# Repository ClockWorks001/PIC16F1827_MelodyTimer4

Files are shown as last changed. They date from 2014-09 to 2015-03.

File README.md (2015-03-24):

# PIC16F1827 Melody Timer Project.
---
This is a simple kitchen/cooking timer by [PIC16F1827][1].
It can choose which of 3 minutes, 5 minutes and 10 minutes.

## Description

This is a simple kitchen/cooking timer by [PIC16F1827][1].
It can choose which of 3 minutes, 5 minutes and 10 minutes.
When it became end of time, it sounds a melody.

I use following peripherals for this Melody Timer project.
  *TMR1* (with interrupt. It makes 1mil second interval.)
  *TMR2*
  *ECCP2*(with TMR2. I use it for PWM output. It buzz a piezo sounder.)
  *GPIO*(input x2 for Switches, output x3 for LED1, LED2, LED3)

Other references.
  <https://docs.google.com/spreadsheets/d/1fajrvUh0QQHbjQNBCf9UKNRYu8I2-zE32fsanEHT9bc/edit?usp=sharing>

## Demo

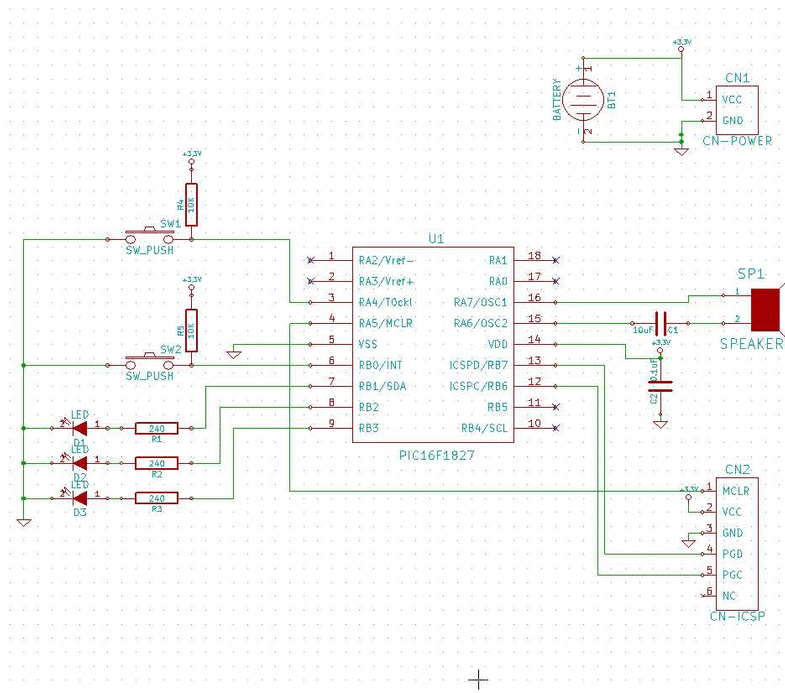
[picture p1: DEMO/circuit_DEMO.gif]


## Prerequisites

I created this project using the free versions of the following tools:
 * [Microchip MPLAB X][2] (v2.3)
 * [Microchip XC8 Compiler][3] (v1.32)
 * [MPLAB Code Configurator][4] (installed as plugin within MPLAB X)
 * [KICAD][6] (BZR4022)

You will need to download and install these tools appropriately before you
can open this project and build it.
I use the [Microchip MPLAB PICkit3 In-Circuit Debugger][5] to program
the chip and debug it.  

## Licence

[MIT](https://github.com/tcnksm/tool/blob/master/LICENCE)

## Author

Hiroshi Murakami  
<https://github.com/ClockWorks001>  

[1]: http://www.microchip.com/wwwproducts/Devices.aspx?dDocName=en538963 "PIC16F1827"
[2]: http://www.microchip.com/pagehandler/en-us/family/mplabx/ "MPLAB X"
[3]: http://www.microchip.com/pagehandler/en_us/devtools/mplabxc/ "MPLAB XC Compilers"
[4]: http://www.microchip.com/pagehandler/en-us/press-release/microchips-free-code-configura.html "MPLAB Code Configurator"
[5]: http://www.microchip.com/Developmenttools/ProductDetails.aspx?PartNO=PG164130 "MPLAB PICkit3 In-Circuit Debugger"
[6]: http://www.kicad-pcb.org/display/KICAD/KiCad+EDA+Software+Suite "KICAD"

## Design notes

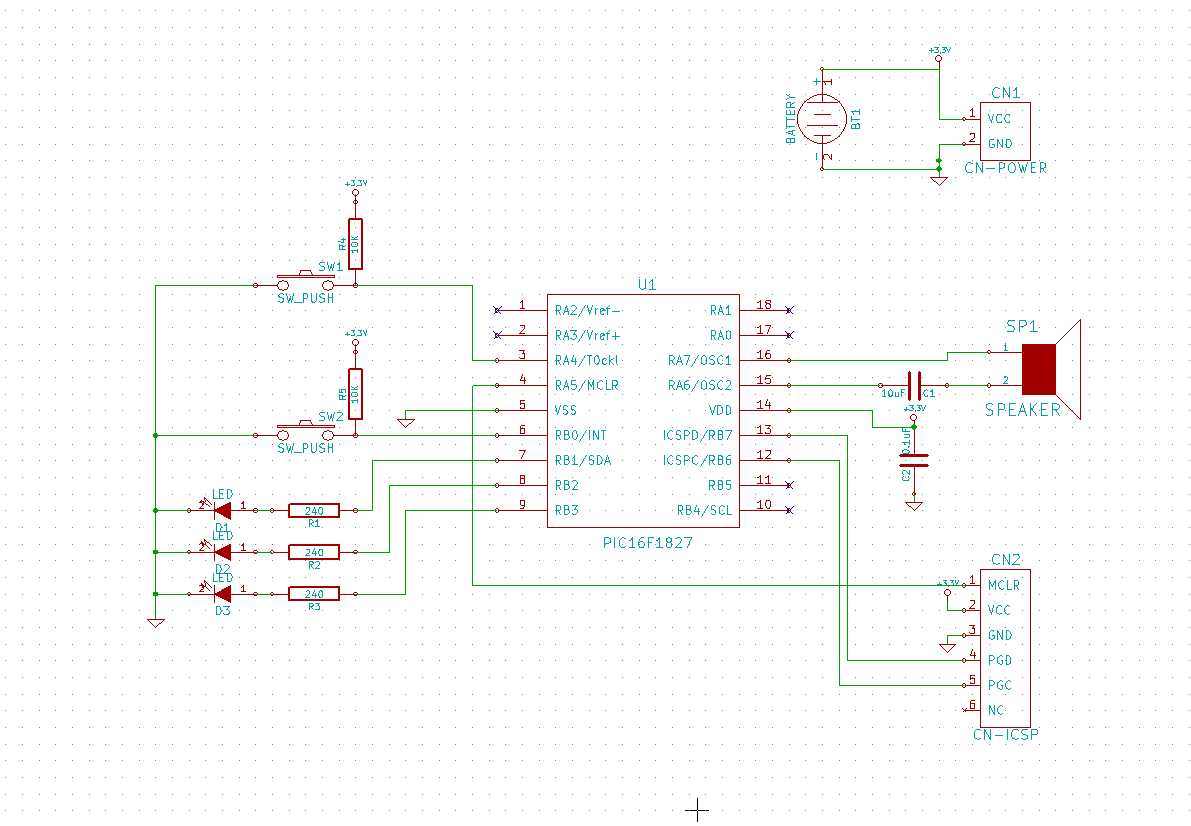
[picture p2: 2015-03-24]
DEMO/circuit_schematic.JPG

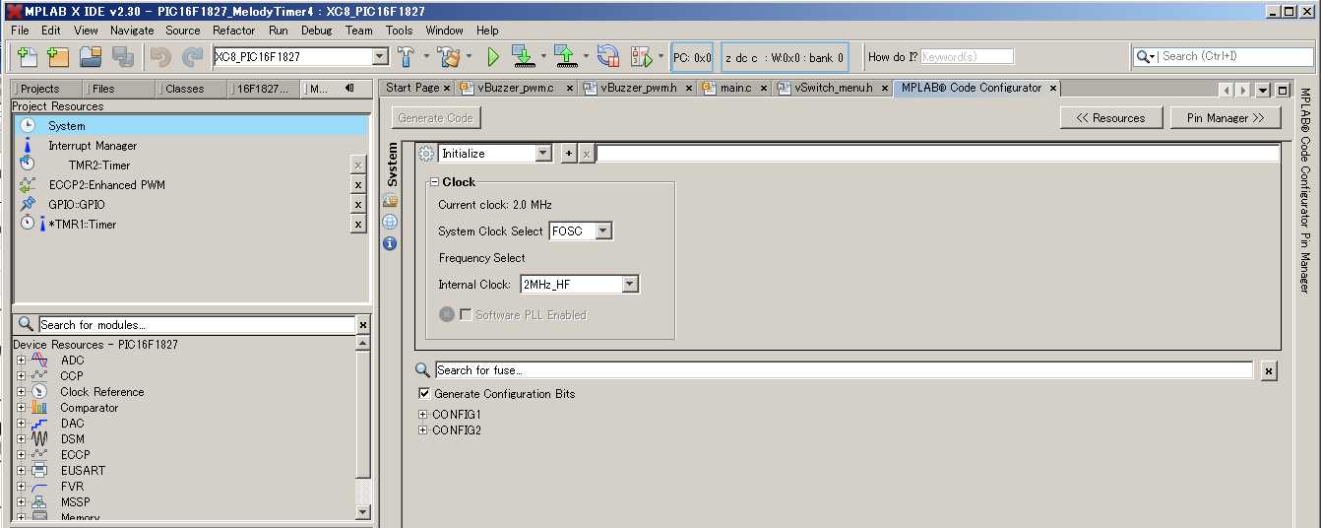
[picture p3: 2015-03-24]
WS000265.JPG

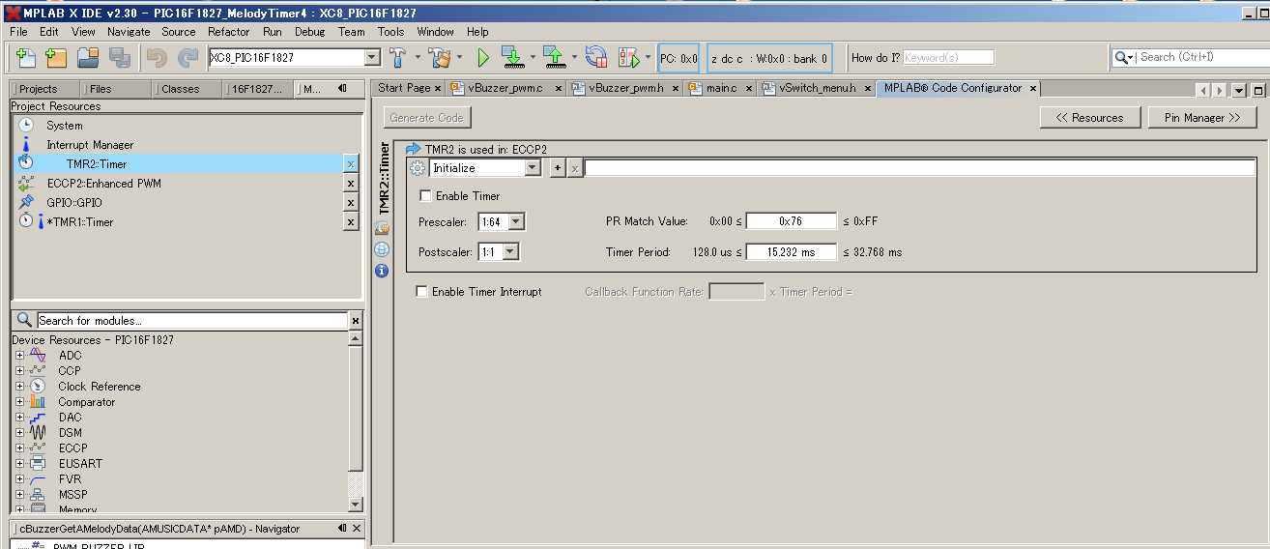
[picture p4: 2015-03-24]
WS000264.JPG

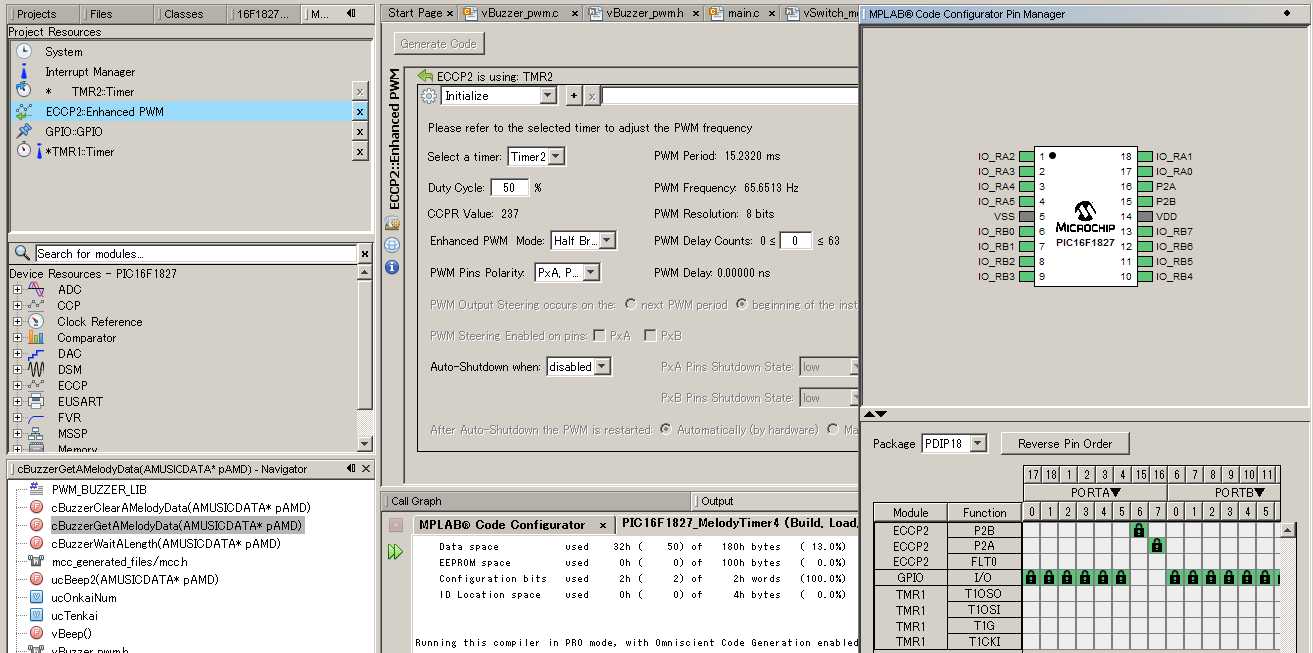
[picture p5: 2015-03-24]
WS000263.JPG

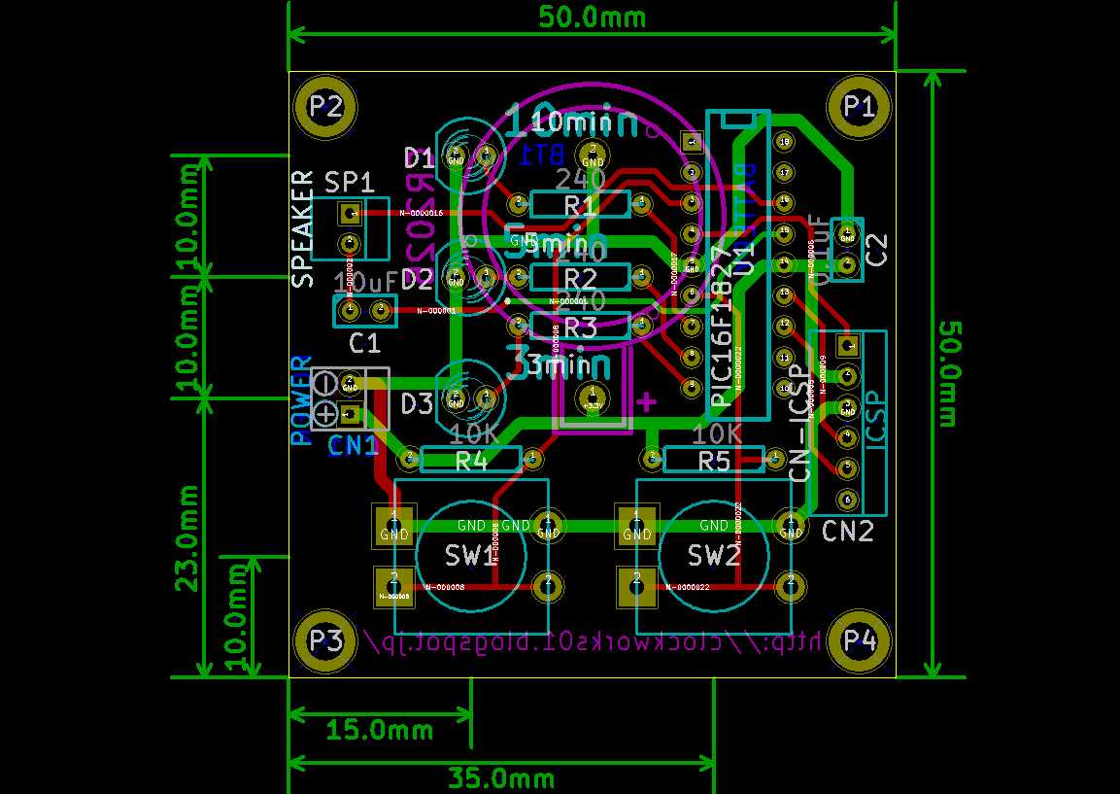
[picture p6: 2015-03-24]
DEMO/circuit_board.JPG

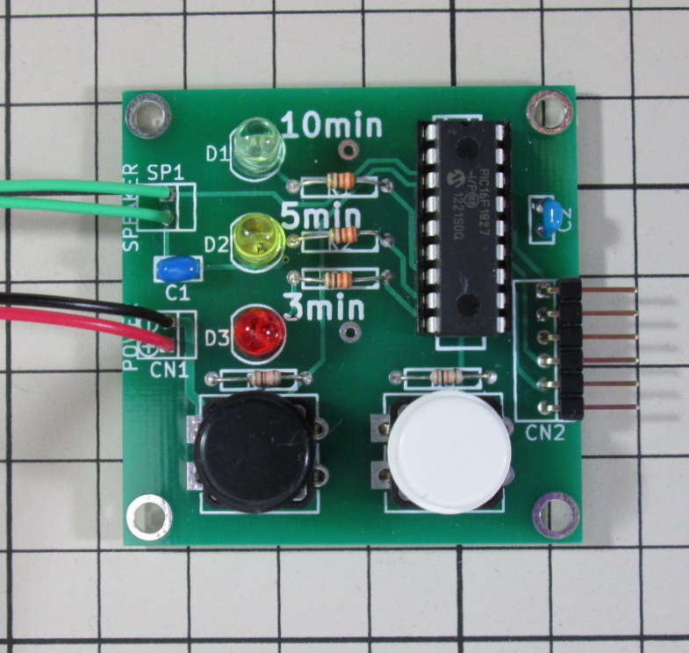
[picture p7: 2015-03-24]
DEMO/circuit_image.JPG

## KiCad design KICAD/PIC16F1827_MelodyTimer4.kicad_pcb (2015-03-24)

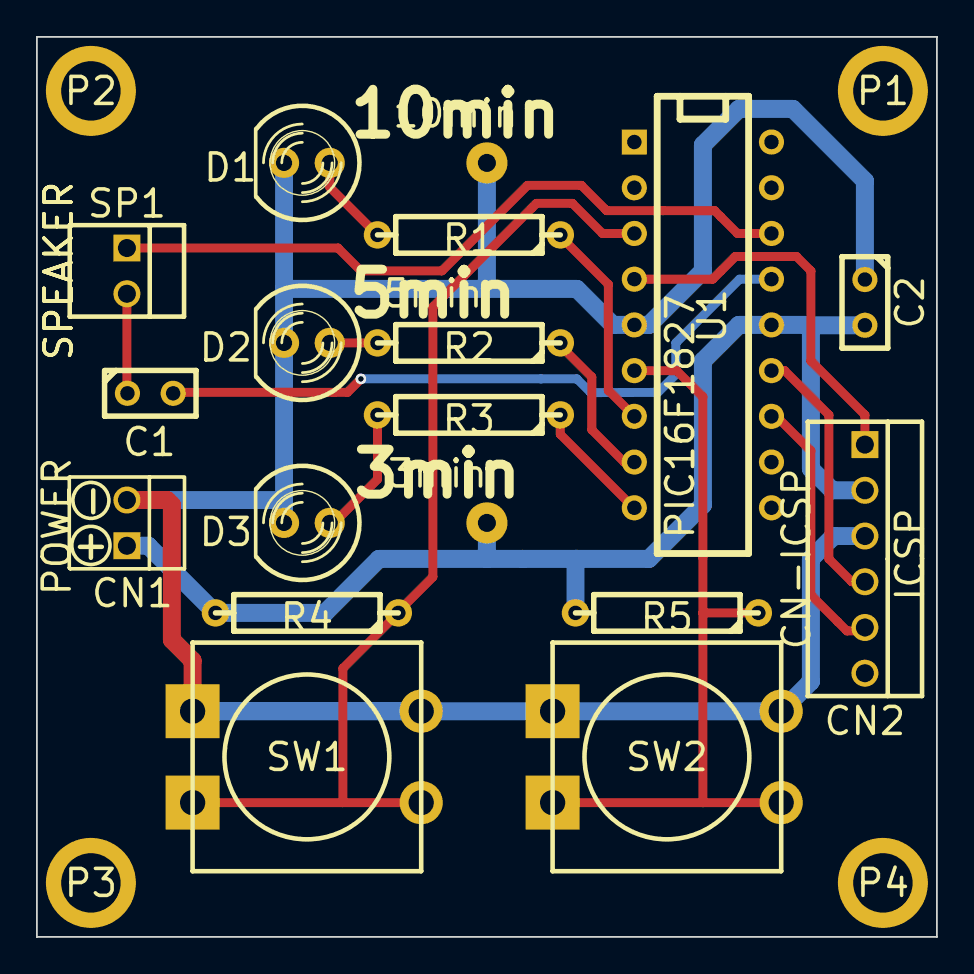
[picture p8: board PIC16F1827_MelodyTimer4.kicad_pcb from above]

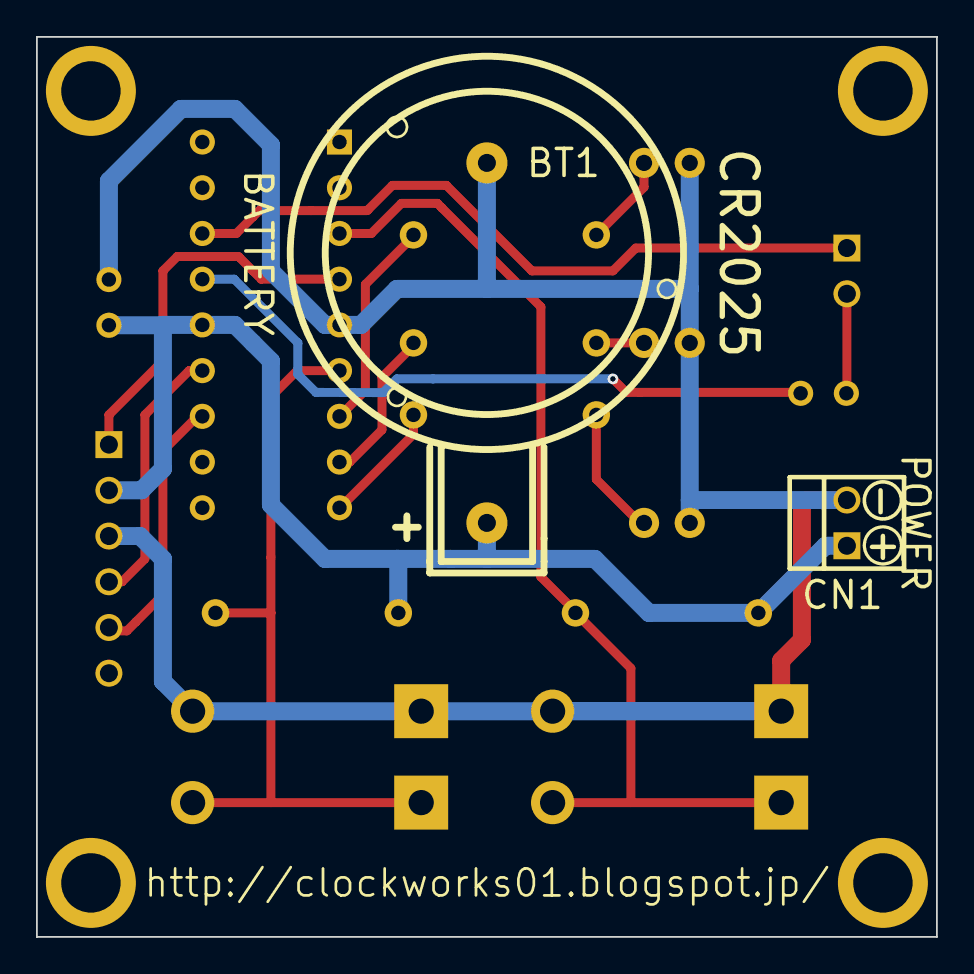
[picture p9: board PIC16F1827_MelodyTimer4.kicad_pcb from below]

Board: 2 copper layers, 50.0 x 50.0 mm, 21 parts (2 on the bottom side), 16 nets.

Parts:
BT1: BATTERY; CR2032H_AK
C1: 10uF; C1_MU
C2: 0.1uF; C1_MU
CN1: POWER; PINHEAD1-2_MU
CN2: CN-ICSP; PINHEAD1-6_MU
D1: 10min; LED-5MM_AK
D2: 5min; LED-5MM_AK
D3: 3min; LED-5MM_AK
P1, P2, P3, P4: PAD3mmX5mm
R1, R2, R3: 240; R4_MU
R4, R5: 10K; R4_MU
SP1: SPEAKER; PINHEAD1-2_MU
SW1, SW2: SW_PUSH-12mm_AK
U1: PIC16F1827; DIP-18__300_MU

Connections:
+3.3V: BT1.1, C2.2, CN1.1, CN2.2, R4.2, R5.2, U1.14
GND: BT1.2, C2.1, CN1.2, CN2.3, D1.2, D2.2, D3.2, SW1.1, SW2.1, U1.5
unnamed: C1.2, U1.15
unnamed: C1.1, SP1.2
unnamed: CN2.5, U1.12
unnamed: CN2.1, U1.4
unnamed: R3.1, U1.9
unnamed: R4.1, SW1.2, U1.3
unnamed: CN2.4, U1.13
unnamed: SP1.1, U1.16
unnamed: R1.1, U1.7
unnamed: D1.1, R1.2
unnamed: R2.1, U1.8
unnamed: D2.1, R2.2
unnamed: D3.1, R3.2
unnamed: R5.1, SW2.2, U1.6

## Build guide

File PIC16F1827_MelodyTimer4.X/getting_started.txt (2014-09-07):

This project is a general template file for the PIC16 Family of
microcontrollers.  It's purpose is to provide a project shell for users to
get started designing their own applications.  Final qualification and testing
of this project is left to the user.

ADVANCED USER TIP

From the main menu, refer to the Task list by going to Window > Tasks (Ctrl+6).
As long as the task window is not configured to filter out any tasks,
the getting started TODO list embedded in this project will be displayed.

Make sure the 'Show tasks for the main project and for the open projects which
depend on it' option is selected on the left hand side of the Tasks window so
that tasks related to other projects are not active.

HOW TO ADD YOUR OWN CODE TO A TEMPLATE

STEP 1

First install the appropriate C compiler if you have not done so already.

See www.microchip.com/compilers

Next, build this project by clicking the Clean and Build Icon (the hammer and
broom symbol) in the MPLAB X IDE Toolbar.  If this project builds, then you are
ready to make changes for your own application.  If the project does not build,
you need to troubleshoot why the project does not build before moving on.

STEP 2

Embed your device's configuration bits into the code.  Instructions for this
are commented in configuration_bits.c

STEP 3

Unless interrupts are not used in your application, fill in the interrupt
vector code.  Code stubs are provided in interrupts.c.  Check the device
datasheet to confirm that you are servicing all the relevant enabled
interrupts in your application within the ISR.  Note that it is important
to check interrupt flags in sequence within one conditional statement to
avoid interrupt contention which could result in corrupting the interrupt
context.

STEP 4

Define system parameters such as the system operating frequency in system.h.

If your device stores an oscillator calibration value at the end of program
memory, incorporate the _READ_OSCCAL_DATA() function in system.c.  The device
datasheet will tell you if calibration data is stored at the end of the
device memory.

Add system level functions to system.h and system.c.  For example, if
you want a function to determine the reset source of the device to know if you
need to backup data, do an oscillator switch, enter a low power mode, etc...
these types of functions may be added to system.c and prototypes can go in
system.h.

STEP 5

Add user level functions to user.h and user.c.  User level functions are
functions that initialize I/O, initialize user peripherals like the ADC,
compute user algorithms, perform calculations on sampled user data, and so on.
User function prototypes and macros may be placed in user.h, and user
functions themselves may go in user.c

STEP 6

Add code to main.c on the line that says <INSERT USER APPLICATION CODE HERE>.
For example, here you would call functions in user.c or system.c, or possibly
setup your own state machine or primary code loop.

Global variables may be added to main.c as well.  As a general practice, macros
and prototypes may go in header files, but variable declarations should not
go in .h files.  Variable declarations should be placed in .c files.

STEP 7

Design the rest of your application.  Add new files to the application, and
test the finished product.

STEP 8

Document what the project does and include other project information in
project_information.txt.

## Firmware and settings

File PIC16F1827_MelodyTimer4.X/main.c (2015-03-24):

/******************************************************************************/
/* Files to Include                                                           */
/******************************************************************************/

#include <xc.h>         /* XC8 General Include File */

#include <stdint.h>        /* For uint8_t definition */
#include <stdbool.h>       /* For true/false definition */

#include "mcc_generated_files/mcc.h"
#include "user.h"          /* User funct/params, such as InitApp */
#include "vClock01.h"
#include "vLED.h"
#include "vSwitch_menu.h"
#include "vBuzzer_pwm.h"


/******************************************************************************/
/* User Global Variable Declaration                                           */
/******************************************************************************/

/* i.e. uint8_t <variable_name>; */

//#define SW1_ON  IO_RA4_GetValue() == 0
//#define SW1_OFF IO_RA4_GetValue() == 1
//#define SW2_ON  IO_RA5_GetValue() == 0
//#define SW2_OFF IO_RA5_GetValue() == 1

/******************************************************************************/
/* Main Program                                                               */
/******************************************************************************/
void main(void)
{
	SYSTEM_Initialize();

    /* Configure the oscillator for the device */
    OSCILLATOR_Initialize();

    /* Initialize I/O and Peripherals for application */
    InitApp();

	// Start Peripherals
	INTERRUPT_PeripheralInterruptEnable();
	INTERRUPT_GlobalInterruptEnable();
                        INTCONbits.IOCIF = 0;
                        INTCONbits.IOCIE = 1;
	TMR1_StartTimer();
	TMR2_StartTimer();
    // User add cording
    vClock01_Clear();

    while(1)
    {
        /* TODO <INSERT USER APPLICATION CODE HERE> */
        vClock01();
        if (cFlag1mSec_ON()){
            vMenuForMelody();
        }
        if (cFlag10mSec_ON()){
            vSW1_Check();
            vSW2_Check();
            vLEDBlink01();
            vMenuForSW2();
            vMenuForSW1();
        }
		
    }

}

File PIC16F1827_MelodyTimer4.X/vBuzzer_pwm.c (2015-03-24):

/*************************************************
*  Making music module by PWM
*************************************************/
#define BUZZER_PWM_LIB

#include <xc.h>         // XC8 General Include File
#include "mcc_generated_files/mcc.h"
#include "vBuzzer_pwm.h"

/*******************************
*  stop buzzer
*******************************/
void vBuzzerStop(void)
{
    // CCP2M P2AP2Chi_P2BP2Dhi; P2M halfbridge; DC2B 16;
    CCP2CON = 0x00;     // PWM clear
    PORTAbits.RA6= 0;   // PWM output pin is low
    PORTAbits.RA7= 0;   // PWM output pin is low
    TMR2_StopTimer();	// Timer2 stop
}

/*******************************
*  restart buzzer
*******************************/
void vBuzzerReStart(void)
{
    EPWM2_Initialize();     // PWM initialize
    TMR2_StartTimer();		// Timer2 start
}

/*******************************
*  vBuzzerSetPWM
*******************************/
unsigned char ucTenkai, ucOnkaiNum;
void vBuzzerSetPWM(AMELODY_DATA* pAMD)
{
    ucTenkai = ucTenkaiTBL[(pAMD->uAM.F.ucScale >> 4) & 0b00000111];
    ucOnkaiNum = pAMD->uAM.F.ucScale & 0b00001111;

    if(ucOnkaiNum == 0){
        vBuzzerStop();			//PWM_OFF
    }else{
        T2CONbits.T2CKPS = (ucTenkai >> 1);
        PR2 = ucOnkaiTBL[ucTenkai & 0b00000001][ucOnkaiNum] - 1;
        CCPR2L	= PR2 / 2;		//rate 50%
//		CCPR2H	= 0x00;
        vBuzzerReStart();
    }
}

/*******************************
*  cSetAMusicData01
*******************************/
char cSelectAMusicData01(AMELODY_DATA* pAMD)
{
    pAMD->uspMusic =  (unsigned short *) usMusicData;
	return 0;
}
/*******************************
*  cBuzzerClearAMelodyData
*******************************/
char cBuzzerClearAMelodyData(AMELODY_DATA* pAMD)
{
    pAMD->ucMusicPosition = 0;
    pAMD->uAM.usAMelody = usMusicData[pAMD->ucMusicPosition];
    vBuzzerReStart();
	return 0;
}

/*******************************
*  cBuzzerGetAMelodyData
*   return: 1:Playing 0:End of Music
*   input : AMELODY_DATA
*   output: return, AMELODY_DATA
*******************************/
char cBuzzerGetAMelodyData(AMELODY_DATA* pAMD)
{
//    pAMD->uAM.usAMelody = usMusicData[pAMD->ucMusicPosition];
    pAMD->uAM.usAMelody = *(pAMD->uspMusic + pAMD->ucMusicPosition );
    pAMD->usLength = pAMD->uAM.F.ucLength * BASIC_LENGTH;
    pAMD->ucMusicPosition ++;
	if(pAMD->uAM.usAMelody == 0xFFFF){
		return 0;
	} else {
		return 1;
	}
}

/*******************************
*  cBuzzerWaitALength
*   return: 1:Waiting 0:End of Length
*   input : AMUUSICDATA
*   output: return, AMELODY_DATA
*******************************/
char cBuzzerWaitALength(AMELODY_DATA* pAMD)
{
    pAMD->usLength--;
	if(pAMD->usLength == 0){
		return 0;
	} else if(pAMD->usLength <= GAP_LENGTH) { //音の切れ目を作る
		vBuzzerStop();			//PWM_OFF
		return 1;
	} else {
		return 1;
	}
}

/*******************************
*  vMenuForMelody
*   return: -
*   input : -
*   output: Melody
*******************************/
void vMenuForMelody(void)
{
    switch (eMenu_Melody_Status) {

        case    eMenu_Melody_Start :
                cSelectAMusicData01(&sAMD);               //select a music.
                cBuzzerClearAMelodyData(&sAMD);        //set start point of a Melody data.
                eMenu_Melody_Status++;
                break;

    //Play melody loop start from here------------------------------
        case    eMenu_Melody_get_a_Data :               // get a Melody data
                if(cBuzzerGetAMelodyData(&sAMD)){
                    eMenu_Melody_Status++;
                }else{
                    eMenu_Melody_Status=eMenu_Melody_Start;
                }
//                            vLEDBlink01();
                break;

        case    eMenu_Melody_set_a_Beep :               //set a scale to a PWM peripheral
                vBuzzerSetPWM(&sAMD);
                eMenu_Melody_Status++;
                break;

        case    eMenu_Melody_wait_a_Tone :               //wait a melody longth
                if(cBuzzerWaitALength(&sAMD)){
                    //wait!
                }else{
                    eMenu_Melody_Status=eMenu_Melody_get_a_Data;
                }
                break;
    //Play melody loop end------------------------------------------
        case    eMenu_Melody_stop :               //wait a musical note
            vBuzzerStop();
    //            eMenu_Melody_Status = eMenu_Melody_get_a_Data;
                break;
        default:
                eMenu_Melody_Status = eMenu_Melody_Start;
    }

}

/*******************************
*  ucMusicPosition
*   return: ucMusicPosition
*******************************/
unsigned char ucMusicPosition(void)
{
    return (sAMD.ucMusicPosition);
}

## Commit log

2014-11-03 switch menu making
2015-02-15 compile up for cooking timer with 3,5,10min
2015-03-24 phase 1 programing done. pcb design done.
2015-03-24 phase 1 programing done. pcb design done.(2)
2015-03-24 phase 1 programing done. pcb design done.(3)
    [.kicad_pcb.kicad_pcb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]
